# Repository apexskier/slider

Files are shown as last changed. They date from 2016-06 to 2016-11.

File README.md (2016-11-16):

# Slider

Arduino driven mechanical video slider.

[Parts list](https://docs.google.com/a/camlittle.com/spreadsheets/d/1xlj7D98955wYuXj9ept1h3pb_NClaukpYvvVbXTrUsw/edit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)

## Finished project

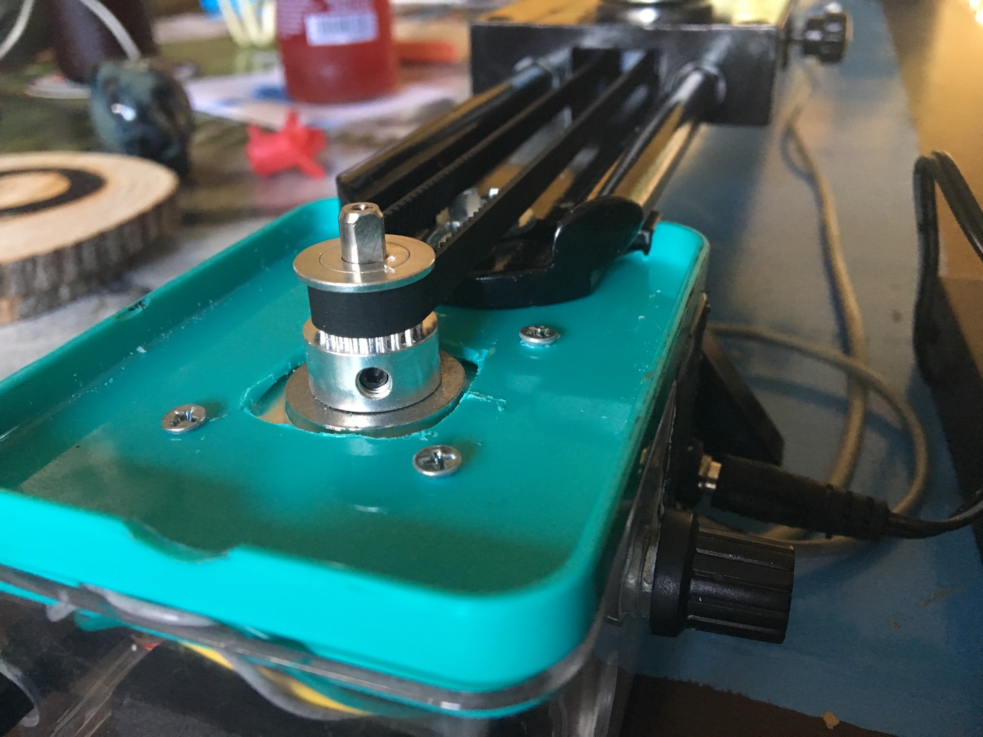
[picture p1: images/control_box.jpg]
Control box and motor housing


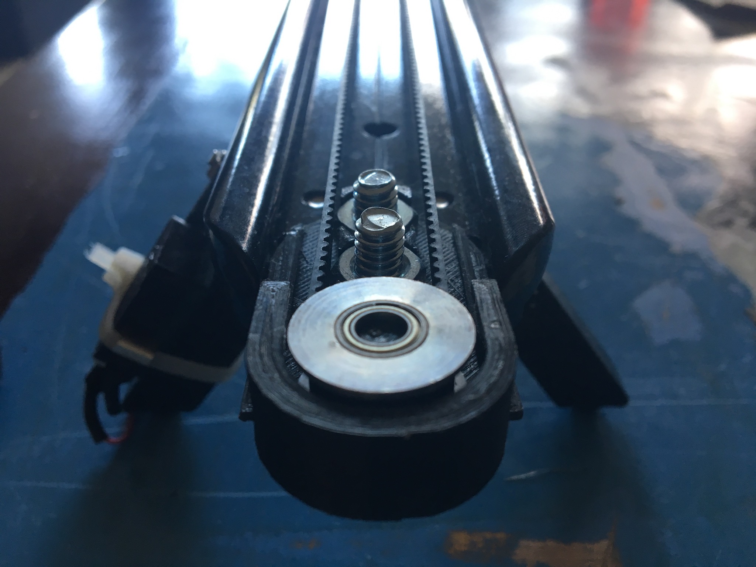
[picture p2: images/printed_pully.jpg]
Timing belt pully and 3D printed mount


## Features

- Auto calibration
- Simple oscillation between each end
- Single direction movement towards the end
- Speed control

## Code

The code is controlled by a basic state machine, paired with global application
state and event triggers. When powered on, the system enters the
CalibratingFindLeft state.

Each button produces buttonDown and buttonUp events as they are pressed and
released.

These are the main state transitions:

```
Stopped
  - main buttonUp -> OscillatingLeft
  - left buttonUp -> MoveLeft
  - right buttonUp -> MoveRight
OscillatingLeft
  - position at left side -> OscillatingRight
  - main buttonDown -> Stopped
OscillatingRight
  - position at right side -> OscillatingLeft
  - main buttonDown -> Stopped
MoveLeft
  - position at left side -> Stopped
MoveRight
  - position at right side -> Stopped
CalibratingFindLeft
  - left buttonDown -> CalibratingFindRight
    (record "0" point)
CalibratingFindRight
  - right buttonDown -> CalibratingReset
    (record slider length)
CalibratingReset
  - position past center -> Stopped
```

In most cases, when in motion buttonDown events on the direction of motion's
switch automatically adjust the internal calibration. There are a few other
event handling checks to safeguard against unexpected behavior.

## Resources

These two DIY slider designs contributed heavily towards ours.

- http://s.co.tt/2015/04/24/diy-motion-control-camera-slider/
- https://learn.adafruit.com/bluetooth-motorized-camera-slider

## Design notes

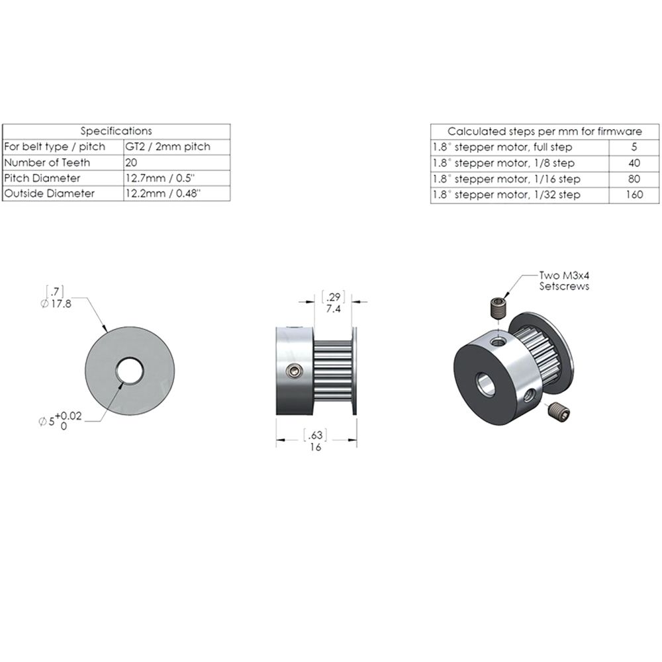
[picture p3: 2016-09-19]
resources/s-l1600.jpg

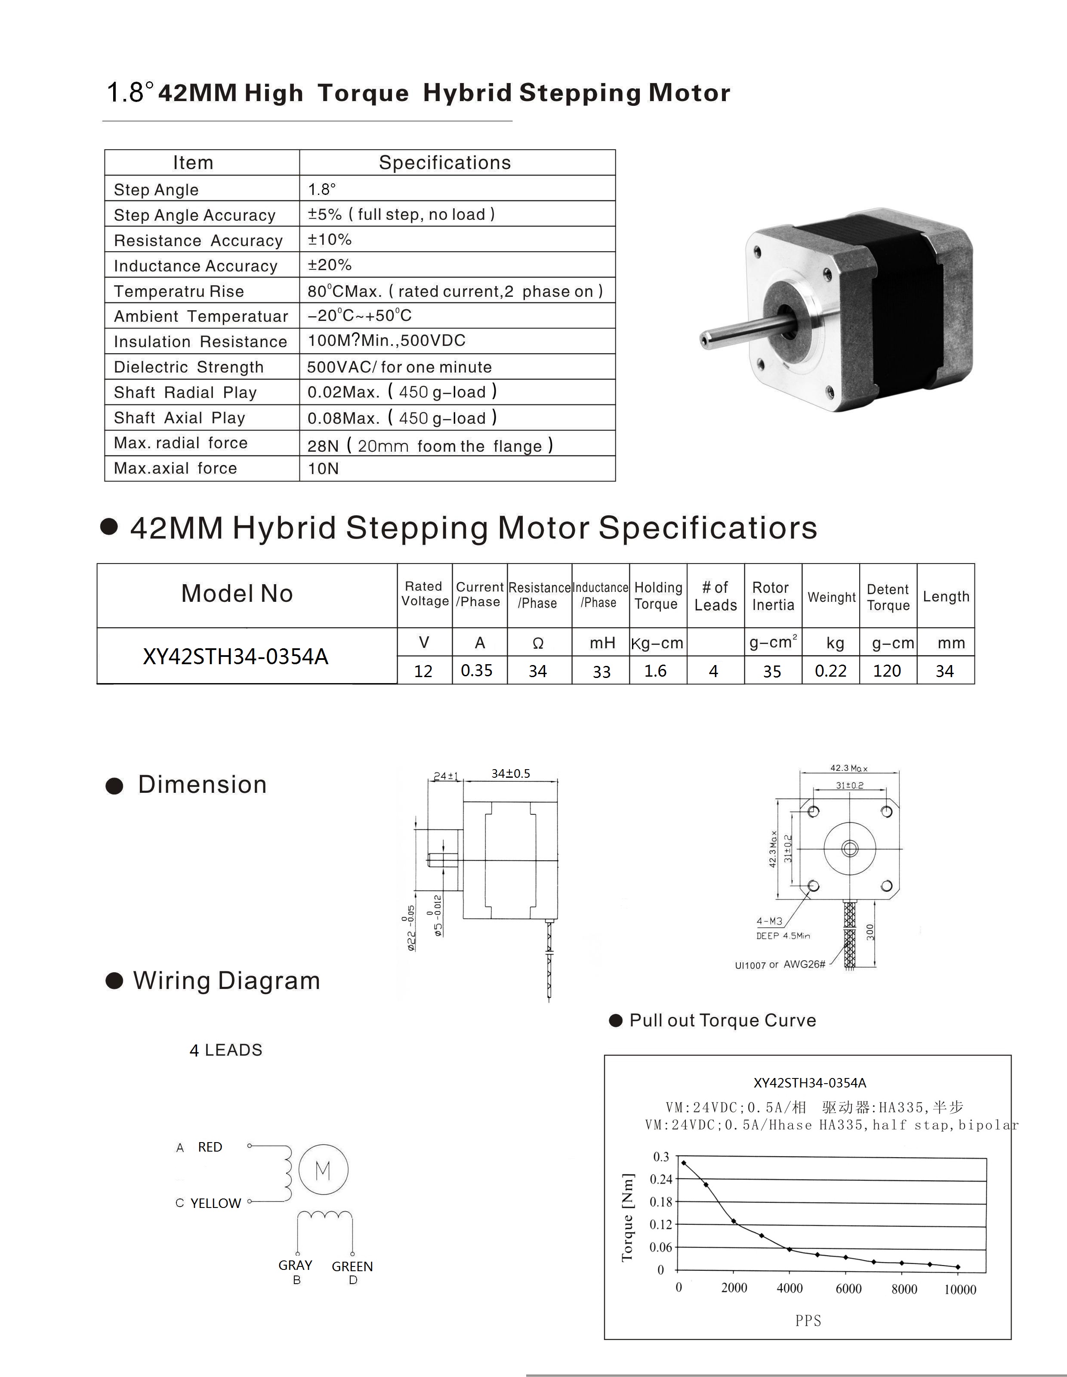
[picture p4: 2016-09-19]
resources/C140-A+datasheet.jpg

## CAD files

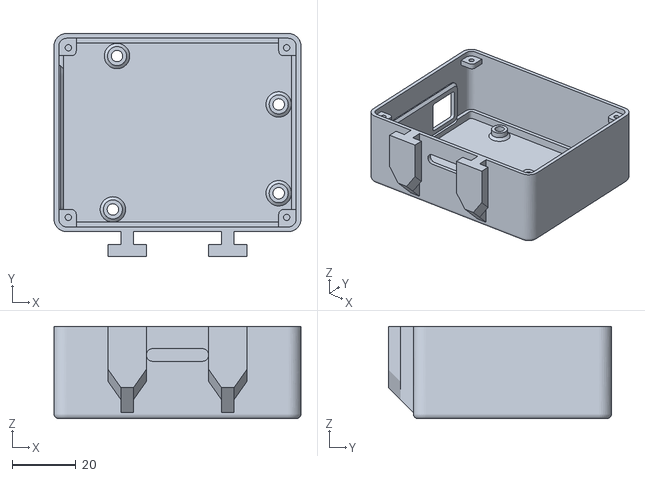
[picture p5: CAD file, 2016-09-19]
resources/Bluetooth_Motorized_Camera_Slider/enclosure-box.stl
77.6 x 70.1 x 29.0

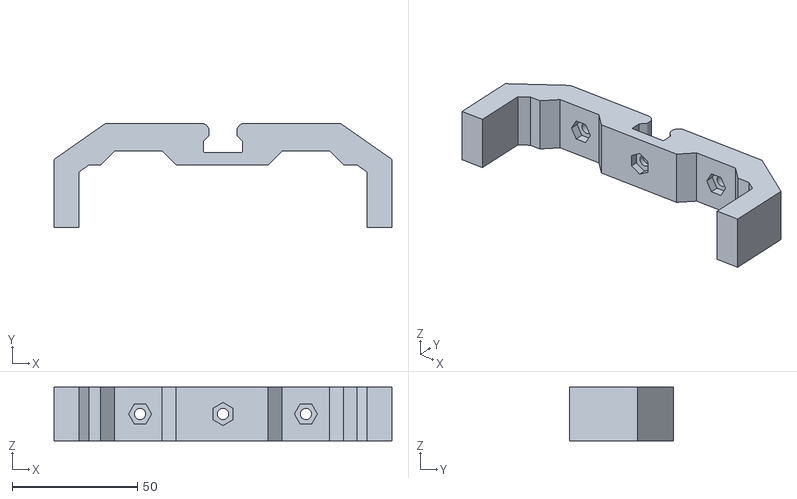
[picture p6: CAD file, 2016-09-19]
resources/Bluetooth_Motorized_Camera_Slider/rail-foot.stl
135.0 x 41.6 x 21.5

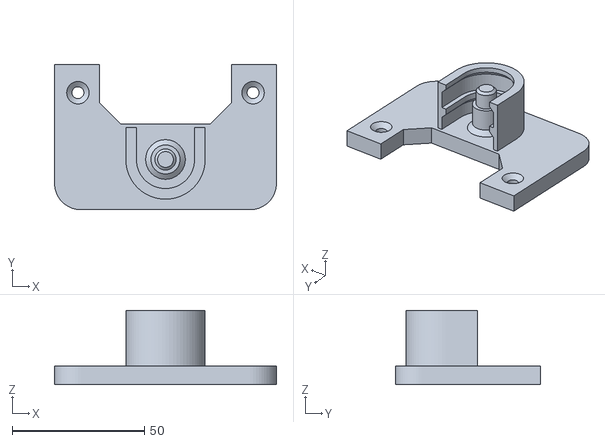
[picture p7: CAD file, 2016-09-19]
resources/Bluetooth_Motorized_Camera_Slider/bearing-mount.stl
83.9 x 55.0 x 28.0

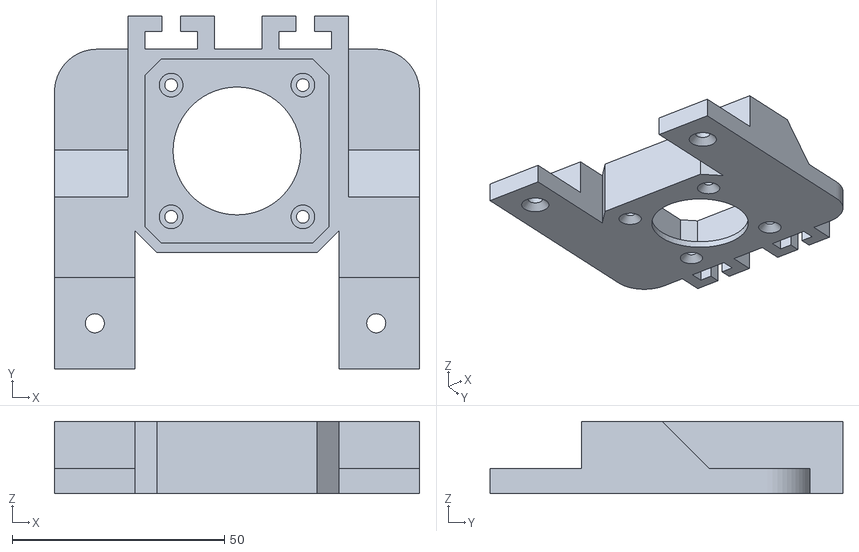
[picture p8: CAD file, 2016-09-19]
resources/Bluetooth_Motorized_Camera_Slider/motor-mount.stl
85.9 x 83.0 x 17.0

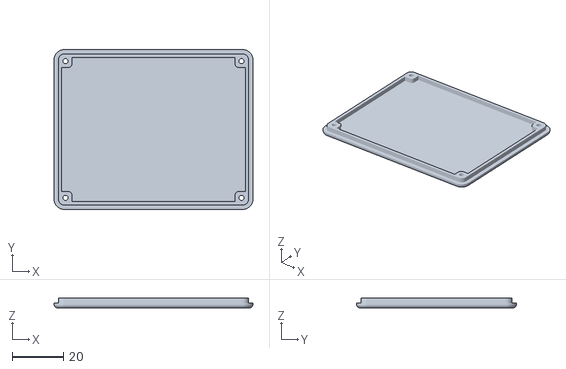
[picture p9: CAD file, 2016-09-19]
resources/Bluetooth_Motorized_Camera_Slider/enclosure-top.stl
77.6 x 62.3 x 4.00

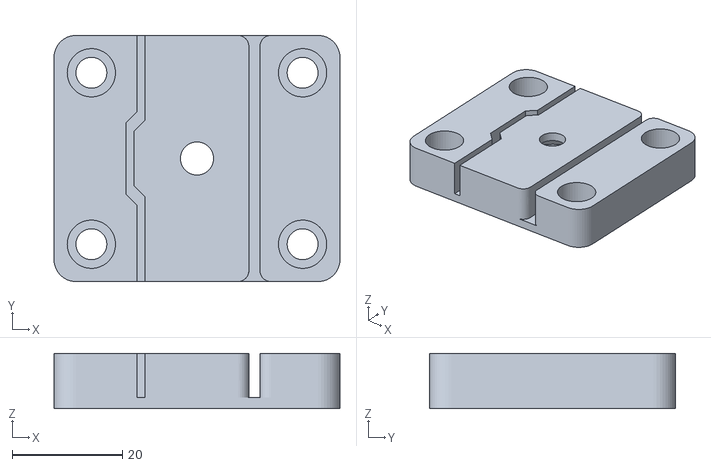
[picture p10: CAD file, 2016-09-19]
resources/Bluetooth_Motorized_Camera_Slider/camera-mount.stl
51.8 x 44.6 x 10.0

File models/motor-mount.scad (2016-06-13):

// rule of thumb
// .2 mm space for friction fit
// .4 mm space for loose fit

wallWidth = 2;

fourCorners = [0, 90, 180, 270];

motorWidth = 42.3 + .2 * 2;
motorCircleDiameter = 22 + .4 * 2;
motorHeight = 34 + .5;
motorDistanceBetweenScrews = 31 + .2;
motorCornerInset = 4;
motorCornerInsetSide = sqrt(2 * pow(motorCornerInset, 2));
motorEdgeHeight = 6;
motorScrewThreadDiameter = 2.7 + .4 * 2;
motorScrewDiameter = 5 + .2 * 2;
motorCounterSinkDepth = 1.8;

module screwHole() {
    translate([0, 0, -1]) {
        cylinder(h = 20, d = motorScrewThreadDiameter, $fn = 80);
    }
    cylinder(h = motorCounterSinkDepth, d1 = motorScrewDiameter, d2 = motorScrewThreadDiameter, $fn = 80);
}

module motorScrewHole() {
    translate([motorDistanceBetweenScrews / 2, motorDistanceBetweenScrews / 2, -0.001]) {
        screwHole();
    }
}

module edgeCutOff() {
    translate([motorWidth / 2, motorWidth / 2, 0]) {
        rotate(45, [0, 0, 1]) {
            translate([-motorCornerInsetSide / 2, -motorCornerInsetSide / 2, 0]) {
                cube([motorCornerInsetSide, motorCornerInsetSide, motorEdgeHeight]);
            }
        }
    }
}

module motorMount() {
    difference() {
        union() {
            difference() {
                translate([-motorWidth / 2 - wallWidth, -motorWidth / 2 - wallWidth, 0]) {
                    cube([motorWidth + wallWidth * 2, motorWidth + wallWidth * 2, motorEdgeHeight]);
                }

                difference() {
                    translate([-motorWidth / 2, -motorWidth / 2, 0]) {
                        cube([motorWidth, motorWidth, motorEdgeHeight + 1]);
                    }

                    for (d = fourCorners) {
                        rotate(d, [0, 0, 1]) edgeCutOff();
                    }
                }
            }

            translate([-motorWidth / 2, -motorWidth / 2, 0]) {
                cube([motorWidth, motorWidth, 2]);
            }
        }

        translate([0, 0, -1]) {
            cylinder(h = 40, d = motorCircleDiameter);
        }

        for (d = fourCorners) {
            rotate(d, [0, 0, 1]) motorScrewHole();
        }
    }
}

translate([0, -(motorWidth + wallWidth * 2) / 2, 0]) {
    rotate(180, [0, 1, 0]) {
        motorMount();
    }
}

mountNutDiameter = 12.8 + .2 * 2;
mountNutHeight = 4.6;
mountScrewDiameter = 6.2 + .4 * 2;
// ensure this is < timing belt diameter
mountDiameter = mountNutDiameter + 3;
mountHoleBetween = 4.2;
mountDistanceToLegs = 4;
mountHoleDiameter = 8;
// distance between middle of two mounting holes
mountSpaceBetween = 4 + 4.2 + 4;

baseThickness = 1.5;
baseLengthExtra = mountDiameter + mountSpaceBetween;
baseWidth = 30 - .2;

module mountNutCutout() {
    translate([0, 0, -50]) {
        linear_extrude(height = 100) {
            circle(d = mountScrewDiameter, $fn = 60);
        }
    }
}

rotate(180, [0, 1, 0]) {
    // above base
    translate([0, 0, baseThickness]) {
        // nut holders
        translate([0, mountDiameter / 2, 0]) {
            difference() {
                hull() {
                    linear_extrude(height = mountNutHeight) {
                        circle(d = mountDiameter, $fn = 30);
                    }

                    translate([0, mountSpaceBetween, 0]) {
                        linear_extrude(height = mountNutHeight) {
                            circle(d = mountDiameter, $fn = 30);
                        }
                    }
                }

                translate([-mountDiameter, mountSpaceBetween + mountDiameter / 2 - wallWidth * 2, -20]) {
                    cube([mountDiameter * 2, 20, 30]);
                }

                translate([0, 0, -1]) {
                    linear_extrude(height = mountNutHeight + 2) {
                        circle(d = mountNutDiameter, $fn = 6);
                    }

                    translate([0, mountSpaceBetween, 0]) {
                        linear_extrude(height = mountNutHeight + 2) {
                            circle(d = mountNutDiameter, $fn = 6);
                        }
                    }
                }
            }
        }
    }
}

boxWidth = motorWidth + (wallWidth + wallWidth + 6.8 + 7) * 2;
echo("boxWidth - walls: ", boxWidth - wallWidth * 4);
boxDepth = motorWidth + wallWidth * 2 + baseLengthExtra + 20;
difference() {
    translate([-boxWidth / 2, -(boxDepth - baseLengthExtra), -wallWidth * 2]) {
        translate([0, 0, wallWidth]) {
            cube([boxWidth, boxDepth, wallWidth]);
        }
        difference() {
            translate([wallWidth, wallWidth, -wallWidth]) {
                cube([boxWidth - wallWidth * 2, boxDepth - wallWidth * 2, wallWidth * 2]);
            }
            translate([wallWidth * 2, wallWidth * 2, -wallWidth * 2]) {
                cube([boxWidth - wallWidth * 4, boxDepth - wallWidth * 4, wallWidth * 4]);
            }
        }
    }

    translate([0, mountDiameter / 2, -1]) {
        mountNutCutout();

        translate([0, mountSpaceBetween, 0]) {
            mountNutCutout();
        }
    }

    translate([0, -(motorWidth + wallWidth * 2) / 2, 0]) {
        rotate(180, [0, 1, 0]) {
            translate([0, 0, -1]) {
                cylinder(h = 40, d = motorCircleDiameter);
            }

            for (d = fourCorners) {
                rotate(d, [0, 0, 1]) motorScrewHole();
            }
        }
    }

    translate([-boxWidth / 2 + 8, 0, 0.01]) {
        translate([0, baseLengthExtra - 8, 0]) {
            rotate(180, [0, 1, 0]) {
                screwHole();
            }
        }

        translate([0, -(boxDepth - baseLengthExtra - 8), 0]) {
            rotate(180, [0, 1, 0]) {
                screwHole();
            }
        }
    }

    translate([boxWidth / 2 - 8, 0,  0.01]) {
        translate([0, baseLengthExtra - 8, 0]) {
            rotate(180, [0, 1, 0]) {
                screwHole();
            }
        }

        translate([0, -(boxDepth - baseLengthExtra - 8), 0]) {
            rotate(180, [0, 1, 0]) {
                screwHole();
            }
        }
    }
}

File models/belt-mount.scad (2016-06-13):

innerWidth = 21; // - .2 * 2;
outerWidth = innerWidth + 5;
innerLength = 41.7; // - .2 * 2;
outerLength = innerLength + 5;
innerHeight = 9.5;
channelDepth = .1;
channelWidth = 2; // - .2 * 2;
boltHeadDiameter = 11; // + .4 * 2;
boltShaftDiameter = 6.22; // + .4 * 2;
washerThickness = 1.64;
washerDiameter = 12.16; // + .4 * 2;

beltWidth = 6;
beltThickness = 1.4;
beltThicknessWithoutTeeth = .7;
beltToBeltThickness = beltThickness + beltThicknessWithoutTeeth;
toothThickness = 1;
toothSpacing = .8;

beltSpaceOuter = 13.5;

module baseCube() {
    cube([outerWidth, outerLength, innerHeight], center = true);
}

module baseCutout() {
    translate([innerWidth / 2 - .2, innerLength / 2 - .2, -50]) {
        cube([100, 100, 100]);
    }
}

module railCutout() {
    railspace = beltThickness * 3;
    railfromend = (outerLength + 2) / 4;

    translate([-railspace - beltToBeltThickness - outerWidth / 8, -(outerLength + 2) / 2, -innerHeight / 2 + 2]) {
        intersection() {
            union() {
                // outer (top)
                difference() {
                    cube([beltToBeltThickness + .4, outerLength + 2, innerHeight]);

                    // left
                    translate([railspace, outerLength + 2 - railfromend - beltToBeltThickness, 0]) {
                        rotate(-45, [0, 0, 1]) {
                            translate([-beltToBeltThickness - 100, -10, 0]) {
                                cube([beltToBeltThickness + 100, outerLength + 2, innerHeight]);
                            }
                        }
                    }

                    // right
                    translate([beltToBeltThickness + railspace, railfromend, 0]) {
                        rotate(180 + 45, [0, 0, 1]) {
                            translate([beltToBeltThickness, -10, 0]) {
                                cube([beltToBeltThickness + 100, outerLength + 2, innerHeight]);
                            }
                        }
                    }
                }

                // left
                translate([railspace, outerLength + 2 - railfromend - beltToBeltThickness, 0]) {
                    rotate(-45, [0, 0, 1]) {
                        translate([0, -10, 0]) {
                            cube([beltToBeltThickness + .4, outerLength + 2, innerHeight]);
                        }
                    }
                }

                // right
                translate([beltToBeltThickness + railspace, railfromend, 0]) {
                    rotate(180 + 45, [0, 0, 1]) {
                        translate([0, -10, 0]) {
                            cube([beltToBeltThickness + .4, outerLength + 2, innerHeight]);
                        }
                    }
                }

                // inner
                difference() {
                    translate([railspace, 0, 0]) {
                        cube([beltToBeltThickness + .4, outerLength + 2, innerHeight]);
                    }

                    // right
                    translate([beltToBeltThickness + railspace, railfromend, 0]) {
                        rotate(180 + 45, [0, 0, 1]) {
                            translate([-beltToBeltThickness - 4, -10, 0]) {
                                cube([beltToBeltThickness + 4, outerLength + 2, innerHeight]);
                            }
                        }
                    }

                    // left
                    translate([railspace, outerLength + 2 - railfromend - beltToBeltThickness, 0]) {
                        rotate(-45, [0, 0, 1]) {
                            translate([beltToBeltThickness, -10, 0]) {
                                cube([beltToBeltThickness + 10, outerLength + 2, innerHeight]);
                            }
                        }
                    }
                }
            }

            cube([beltThickness + railspace + .4, outerLength + 2, innerHeight]);
        }
    }
}

// this gives an idea of where the belt will slide
// cube(beltSpaceOuter, center = true);

difference() {
    baseCube();

    // corners
    baseCutout();
    scale([1, -1, 1]) baseCutout();
    scale([-1, 1, 1]) baseCutout();
    scale([-1, -1, 1]) baseCutout();

    translate([0, 0, -50]) {
        cylinder(h = 100, d = boltShaftDiameter + .4 * 2, $fn = 60);
    }
    translate([0, 0, -innerHeight / 2 + 1]) {
        cylinder(h = 100, d = boltHeadDiameter + .2 * 2, $fn = 60);
    }

    translate([0, 1.6, 0]) {
        railCutout();
    }

    beltSlidingWidth = beltThickness * 3;
    translate([(-beltSlidingWidth + beltSpaceOuter - beltThickness) / 2, -(outerLength + 2) / 2, -innerHeight / 2 + 2]) {
        cube([beltSlidingWidth, outerLength + 2, innerHeight]);
    }
}

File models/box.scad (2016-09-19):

// rule of thumb
// .2 mm space for friction fit
// .4 mm space for loose fit

wallWidth = 2;

fourCorners = [0, 90, 180, 270];

motorWidth = 42.3 + .2 * 2;
motorHeight = 34 + .5;
motorCornerInset = 4;
motorCornerInsetSide = sqrt(2 * pow(motorCornerInset, 2));
motorEdgeHeight = 6;
motorScrewThreadDiameter = 2.7 + .4 * 2;

mountNutDiameter = 12.8 + .2 * 2;
// ensure this is < timing belt diameter
mountDiameter = mountNutDiameter + 3;
// distance between middle of two mounting holes
mountSpaceBetween = 4 + 4.2 + 4;

baseThickness = 1.5;
baseLengthExtra = mountDiameter + mountSpaceBetween;
baseWidth = 30 - .2;

boxWidth = motorWidth + (wallWidth + wallWidth + 6.8 + 7) * 2;
boxDepth = motorWidth + wallWidth * 2 + baseLengthExtra + 20;
motorRise = 7.5;
boxHeight = 31.5 + motorRise + wallWidth * 2;

nutDiameter = 7.1 + .4 * 2;

switchHeadSide = 16 + .4 * 2;
dialDiameter = 7 + .4 * 2;
batteryPlugDiameter = 11 + .4;
switchCableWidth = 3.3;
switchCableHeight = 2.3;

module screwHole() {
    linear_extrude(height = boxHeight - wallWidth) {
        circle(d = motorScrewThreadDiameter, $fn = 80);
    }
}

module nut() {
    linear_extrude(height = boxHeight - wallWidth * 6) {
        circle(d = nutDiameter, $fn = 6);
    }
}

module nutHolder() {
    height = 10;
    translate([-7, -7, boxHeight - wallWidth * 3 - .2 - height]) {
        cube([14, 14, height]);
    }
}

module edgeCutOff() {
    translate([motorWidth / 2, motorWidth / 2, 0]) {
        rotate(45, [0, 0, 1]) {
            translate([-motorCornerInsetSide / 2, -motorCornerInsetSide / 2, 0]) {
                cube([motorCornerInsetSide, motorCornerInsetSide, motorEdgeHeight]);
            }
        }
    }
}

module motorMount() {
    union() {
        translate([0, 0, motorRise]) {
            difference() {
                translate([-motorWidth / 2 - wallWidth, -motorWidth / 2 - wallWidth, 0]) {
                    cube([motorWidth + wallWidth * 2, motorWidth + wallWidth * 2, motorEdgeHeight]);
                }

                difference() {
                    translate([-motorWidth / 2, -motorWidth / 2, 0]) {
                        cube([motorWidth, motorWidth, motorEdgeHeight + 1]);
                    }

                    for (d = fourCorners) {
                        rotate(d, [0, 0, 1]) edgeCutOff();
                    }
                }
            }
        }

        translate([-motorWidth / 2 - wallWidth, -motorWidth / 2 - wallWidth, 0]) {
            cube([motorWidth + wallWidth * 2, motorWidth + wallWidth * 2, motorRise]);
        }
    }
}

module switchCable() {
    rotate(90, [1, 0, 0])
        scale([1, switchCableHeight / switchCableWidth, 1])
            cylinder(h = 20, d = switchCableWidth, $fn = 30);
}

motorCtlWidth = 1.65;
motorCtlLength = 27;
translate([motorCtlLength / 2 + wallWidth, -boxDepth + baseLengthExtra + wallWidth * 3, wallWidth]) {
    rotate(90, [0, 0, 1]) {
        difference() {
            translate([0, 0, wallWidth]) {
                cube([motorCtlWidth + wallWidth * 2, motorCtlLength + wallWidth * 2, .6]);
                translate([0, 0, -wallWidth]) {
                    cube([motorCtlWidth + wallWidth * 2, motorCtlLength + wallWidth * 2, wallWidth]);
                }
            }
            translate([wallWidth, wallWidth, wallWidth]) {
                cube([motorCtlWidth, motorCtlLength, 10]);
            }
        }
    }
}

arduWidth = 1;
arduLength = 33.6;
mirror(v = [1, 0, 0])
translate([motorWidth / 2 + wallWidth * 2, -boxDepth + baseLengthExtra + wallWidth * 1, wallWidth]) {
    difference() {
        translate([0, 0, wallWidth]) {
            cube([arduWidth + wallWidth * 2, arduLength + wallWidth * 2, .6]);
            translate([0, 0, -wallWidth]) {
                cube([arduWidth + wallWidth * 2, arduLength + wallWidth * 2, wallWidth]);
            }
        }
        translate([wallWidth, wallWidth, wallWidth]) {
            cube([arduWidth, arduLength, 10]);
        }
    }
}

difference() {
    union() {
        translate([-boxWidth / 2, -(boxDepth - baseLengthExtra), 0]) {
            difference() {
                // remember to account for the floor and the ceiling!
                cube([boxWidth, boxDepth, boxHeight]);
                translate([wallWidth, wallWidth, wallWidth]) {
                    cube([boxWidth - wallWidth * 2, boxDepth - wallWidth * 2, 100]);
                }
                // lip where top attaches
                lipWidth = wallWidth - .4;
                translate([lipWidth, lipWidth, boxHeight - wallWidth * 2 - .2]) {
                    cube([boxWidth - lipWidth * 2, boxDepth - lipWidth * 2, 100]);
                }

                // hide walls
                // translate([-1, -1, wallWidth]) {
                //     cube([boxWidth + 2, boxDepth + 2, boxHeight + 2]);
                // }
            }

            // ftdi channel
            cube([6, 10, 24]);
        }

        // screwmounts
        translate([0, 0, wallWidth]) {
            translate([-boxWidth / 2 + 8, 0, 0]) {
                translate([0, baseLengthExtra - 8, 0]) {
                    nutHolder();
                }

                translate([0, -(boxDepth - baseLengthExtra - 8), 0]) {
                    nutHolder();
                }
            }

            translate([boxWidth / 2 - 8, 0, 0]) {
                translate([0, baseLengthExtra - 8, 0]) {
                    nutHolder();
                }

                translate([0, -(boxDepth - baseLengthExtra - 8), 0]) {
                    nutHolder();
                }
            }
        }
    }

    // screwmounts
    translate([0, 0, wallWidth]) {
        translate([-boxWidth / 2 + 8, 0, 0]) {
            translate([0, baseLengthExtra - 8, 0]) {
                screwHole();
                nut();
            }

            translate([0, -(boxDepth - baseLengthExtra - 8), 0]) {
                screwHole();
                nut();
            }
        }

        translate([boxWidth / 2 - 8, 0, 0]) {
            translate([0, baseLengthExtra - 8, 0]) {
                screwHole();
                nut();
            }

            translate([0, -(boxDepth - baseLengthExtra - 8), 0]) {
                screwHole();
                nut();
            }
        }
    }

    translate([boxWidth / 2, 0, boxHeight / 2]) {
        // dial hole
        translate([0, -motorWidth / 2 - wallWidth, 0]) {
            translate([-10, 0, 0]) {
                rotate(90, [0, 1, 0]) {
                    cylinder(d = dialDiameter, h = 20, $fn = 40);
                }
            }

            translate([-.4, 0, 0]) {
                rotate(90, [0, 1, 0]) {
                    linear_extrude(height = 1) {
                        innerR = 11;
                        outerR = 13.5;
                        difference() {
                            color( [0, 1, 0] ) {
                                translate([0, outerR - innerR, 0])
                                    circle(r = outerR);
                            }

                            circle(r = innerR);

                            color( [0, 0, 1] ) {
                                translate([0, -outerR, 0])
                                    square(outerR * 3);
                            }
                        }
                    }
                }
            }
        }

        // button hole
        translate([-switchHeadSide / 2 - 20, 0, -switchHeadSide / 2])
            cube([100, switchHeadSide, switchHeadSide]);
        sHInside = switchHeadSide + 4;
        translate([-sHInside - wallWidth + .8, -2, -sHInside / 2])
            cube([20, sHInside, sHInside]);
    }

    // FTDI cable
    translate([-boxWidth / 2, -motorWidth - 20, wallWidth * 2]) {
        translate([-5, 0, 0]) {
            cube([20, 2.55 + .4 * 2, 15.2 + .4 * 2]);
        }
    }

    // battery plug
    translate([10 - boxWidth / 2, baseLengthExtra - batteryPlugDiameter / 2 - wallWidth, batteryPlugDiameter / 2 + wallWidth]) {
        rotate(-90, [0, 1, 0]) {
            cylinder(d = batteryPlugDiameter, h = 20, $fn = 40);
        }
    }

    // switch holes
    translate([0, baseLengthExtra + 10, boxHeight / 2]) {
        hull() {
            switchCable();
            translate([0, 0, switchCableHeight]) {
                switchCable();
            }
        }
    }

    translate([boxWidth / 2 - .4, -boxDepth + baseLengthExtra + wallWidth, wallWidth]) {
        rotate(90, [1, 0, 0]) {
            rotate(90, [0, 1, 0]) {
                text("https://github.com/apexskier/slider v1.0.0", size = 3);
            }
        }
    }
}

translate([0, -(motorWidth + wallWidth * 2) / 2, 0]) {
    motorMount();
}

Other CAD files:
models/pully-mount.scad

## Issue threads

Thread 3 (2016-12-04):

Persist calibration information

apexskier, 2016-12-04:
I think I can save the left and right positions/size/whatever to persistent storage and avoid a full calibration on every reboot. This will require some sort of user input pattern to trigger calibration.

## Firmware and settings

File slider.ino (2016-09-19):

#include <AccelStepper.h>

#define DEBUG true
#define MAX_SPEED 220

enum EventType {
  Null,
  ButtonUp,
  ButtonDown
};

class Event {
 public:
  Event() {};
  const static EventType type = Null;
};

class NullEvent: public Event {};

class ButtonEvent: public Event {
 public:
  ButtonEvent(unsigned long timeSince) {
    this->timeSince = timeSince;
  };
  unsigned long timeSince;
};

class ButtonDownEvent: public ButtonEvent {
 public:
  ButtonDownEvent(unsigned long timeSince): ButtonEvent(timeSince) {};
  const static EventType type = ButtonDown;
};

class ButtonUpEvent: public ButtonEvent {
 public:
  ButtonUpEvent(unsigned long timeSince): ButtonEvent(timeSince) {};
  const static EventType type = ButtonUp;
};

class Input {
 public:
  Input(int pin) {
    this->pin = pin;
    this->currentValue = LOW;
    this->lastEvent = Null;
    pinMode(pin, INPUT);

    unsigned long now = millis();
    this->lastChangeTime = 0;
    this->lastUpdateTime = 0;
  };

  /**
   * Update the value and internals of an input and generate events.
   * Rate limited
   */
  void update() {
    unsigned long now = millis();
    if (now - lastUpdateTime <= RATE_LIMIT) {
      return;
    }

    int value = digitalRead(pin);
    // Serial.println("read " + String(value) + " on pin " + String(pin));
    // event will be generated
    if (value != currentValue) {
      if (lastEvent != Null) {
        Serial.println("Warning! Unconsumed event in queue for input " + String(pin));
      }
      if (value) {
        lastEvent = ButtonDown;
        if (DEBUG) {
          Serial.println("GENERATE ButtonDownEvent on " + String(pin));
        }
      } else {
        lastEvent = ButtonUp;
        if (DEBUG) {
          Serial.println("GENERATE ButtonUpEvent on " + String(pin));
        }
      }
      lastChangeTime = now;
      currentValue = value;
    }
    lastUpdateTime = now;
  };

  EventType consumeEvent() {
    if (lastEvent == Null) {
      return Null;
    }
    if (DEBUG) {
      switch (lastEvent) {
        case ButtonUp:
          Serial.println("CONSUME ButtonUpEvent on " + String(pin));
          break;
        case ButtonDown:
          Serial.println("CONSUME ButtonDownEvent on " + String(pin));
          break;
        case Null:
          Serial.println("CONSUME NullEvent on " + String(pin));
          break;
        default:
          Serial.println("CONSUME Unknown Event on " + String(pin));
      }
    }
    EventType e = lastEvent;
    lastEvent = Null;
    return e;
  };

 protected:
  int pin;
  int currentValue;
  unsigned long lastChangeTime;
  unsigned long lastUpdateTime;
  EventType lastEvent;
  const static unsigned long RATE_LIMIT = 10;
};

// const int LED = 13;    // DO NOT USE ----------------- v  ----
AccelStepper stepper(AccelStepper::FULL4WIRE, 10, 11, 12, 13);

const int PADDING = 10;
const float CALIBRATION_SPEED = 100;

long sliderLength = 0;

Input* startButton = NULL;
Input* leftSwitch = NULL;
Input* rightSwitch = NULL;
int speedPotPin = A0;

enum State {
  Stopped,
  OscillatingLeft,
  OscillatingRight,
  MoveLeft,
  MoveRight,
  CalibratingFindLeft,
  CalibratingFindRight,
  CalibratingReset
};

String stateName(State s) {
  switch (s) {
    case Stopped:
      return "Stopped";
    case OscillatingLeft:
      return "OscillatingLeft";
    case OscillatingRight:
      return "OscillatingRight";
    case MoveLeft:
      return "MoveLeft";
    case MoveRight:
      return "MoveRight";
    case CalibratingFindLeft:
      return "CalibratingFindLeft";
    case CalibratingFindRight:
      return "CalibratingFindRight";
    case CalibratingReset:
      return "CalibratingReset";
  }
  return "UnknownState";
}

State currentState = Stopped;

void setSliderSpeed() {
    float speed = analogToSpeed(1023 - analogRead(speedPotPin));
    float currentSpeed = stepper.speed();
    if (abs(abs(currentSpeed) - speed) > 2) {
        if (currentSpeed > 0) {
            stepper.setSpeed(speed);
        } else {
            stepper.setSpeed(-speed);
        }
        if (DEBUG) {
            Serial.println("SETTING SPEED: " + String(speed));
        }
    }
}

float analogToSpeed(int value) {
  //                     v -- max analog value
  return (float(value) / 1023.0) * MAX_SPEED;
}

void startMovingLeft() {
  if (DEBUG) {
    Serial.println("MOVE LEFT");
  }
  int speed = stepper.speed();
  if (speed > 0) {
    speed = -speed;
  }
  stepper.setSpeed(speed);
}

void startMovingRight() {
  if (DEBUG) {
    Serial.println("MOVE RIGHT");
  }
  int speed = stepper.speed();
  if (speed < 0) {
    speed = -speed;
  }
  stepper.setSpeed(speed);
}

void markLeft() {
  int speed = stepper.speed();
  sliderLength = sliderLength - stepper.currentPosition();
  stepper.setCurrentPosition(0);
  stepper.setSpeed(speed);
  if (DEBUG) {
    Serial.println("MARK LEFT");
  }
}

void markRight() {
  sliderLength = stepper.currentPosition();
  if (DEBUG) {
    Serial.println("MARK RIGHT (" + String(sliderLength) + ")");
  }
}

void changeState(State s) {
  if (DEBUG) {
    Serial.println("STATE CHANGE: from " + stateName(currentState) + " to " + stateName(s));
  }
  currentState = s;
}

void setup() {
  startButton = new Input(8);
  leftSwitch = new Input(2);
  rightSwitch = new Input(4);

  stepper.setMaxSpeed(MAX_SPEED);
  stepper.setAcceleration(1);

  // initialize the serial port:
  Serial.begin(9600);

  delay(300);

  // calibrate();
  changeState(CalibratingFindLeft);
  stepper.setSpeed(CALIBRATION_SPEED);
  startMovingLeft();
}

void loop() {
  // Serial.println("-------------------------");
  State loopState = currentState;

  // Read inputs
  startButton->update();
  leftSwitch->update();
  rightSwitch->update();

  EventType startEvent = startButton->consumeEvent();
  EventType leftEvent = leftSwitch->consumeEvent();
  EventType rightEvent = rightSwitch->consumeEvent();

  // Navigate through state machine
  // * Event based
  switch (startEvent) {
    case ButtonUp:
      switch (loopState) {
        case Stopped:
          // TODO: choose direction
          if (stepper.speed() > 0) {
            changeState(OscillatingRight);
          } else {
            changeState(OscillatingLeft);
          }
        break;
        case CalibratingReset:
          changeState(Stopped);
          break;
      }
      break;
    case ButtonDown:
      switch (loopState) {
        case OscillatingLeft:
        case OscillatingRight:
        case MoveLeft:
        case MoveRight:
        case CalibratingReset:
          changeState(Stopped);
          break;
      }
  }

  switch (leftEvent) {
    case ButtonUp:
      switch (loopState) {
        case Stopped:
          changeState(MoveLeft);
          startMovingLeft();
          break;
      }
      break;
    case ButtonDown:
      switch (loopState) {
        case OscillatingLeft:
          markLeft();
          startMovingRight();
          changeState(OscillatingRight);
          break;
        case CalibratingFindLeft:
          markLeft();
          startMovingRight();
          changeState(CalibratingFindRight);
          break;
        case CalibratingReset:
          markLeft();
          startMovingRight();
          changeState(CalibratingFindRight);
          break;
        case MoveLeft:
          markLeft();
          startMovingRight();
          changeState(Stopped);
          break;
      }
  }

  switch (rightEvent) {
    case ButtonUp:
      switch (loopState) {
        case Stopped:
          changeState(MoveRight);
          startMovingRight();
          break;
      }
      break;
    case ButtonDown:
      switch (loopState) {
        case OscillatingRight:
          markRight();
          startMovingLeft();
          changeState(OscillatingLeft);
          break;
        case CalibratingFindRight:
          markRight();
          startMovingLeft();
          changeState(CalibratingReset);
          break;
        case CalibratingReset:
          markRight();
          startMovingLeft();
          changeState(CalibratingFindLeft);
          break;
        case MoveRight:
          markRight();
          startMovingLeft();
          changeState(Stopped);
          break;
      }
  }

  int sliderPosition = stepper.currentPosition();

  // * global state based // TODO: better word than state here
  if (sliderPosition < PADDING) {
    switch (loopState) {
      case OscillatingLeft:
        startMovingRight();
        changeState(OscillatingRight);
        break;
      case MoveLeft:
        startMovingRight();
        changeState(Stopped);
        break;
    }
  } else if (sliderPosition > sliderLength - PADDING) {
    switch (loopState) {
      case OscillatingRight:
        startMovingLeft();
        changeState(OscillatingLeft);
        break;
      case MoveRight:
        startMovingLeft();
        changeState(Stopped);
        break;
    }
  }

  if (loopState == CalibratingReset &&
      sliderPosition < sliderLength / 2) {
    changeState(Stopped);
  }

  if (!(loopState == CalibratingFindLeft ||
        loopState == CalibratingFindRight ||
        loopState == CalibratingReset)) {
    setSliderSpeed();
  }

  // State actions
  switch (loopState) {
    case OscillatingLeft:
    case MoveLeft:
    case OscillatingRight:
    case MoveRight:
    case CalibratingFindLeft:
    case CalibratingFindRight:
    case CalibratingReset:
      stepper.runSpeed();
      break;
    case Stopped:
    default:
      // pass!
      break;
  }
}

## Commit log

2016-05-05 Basic i/o code, basic (not correct) circuit schematic
    [slider.fzz]
2016-05-05 Got calibration v1 working.
2016-05-13 Implemented padding stuff in oscillation.
    [slider.ino]
2016-05-13 Debugged and fixed a bunch of stuff.
    [slider.ino]
2016-05-14 Added README and pully-mount
    [pully-mount.scad]
2016-05-16 Progress
    - Worked on pully mount for actual hardware dimensions and mounting
    - Started on motor mount/electronics enclosure
    - Bugfixes to code
    [motor-mount.scad, pully-mount.scad]
2016-06-13 Updated and adding models.
    [belt-mount.scad, motor-mount.scad, pully-mount.scad]
2016-06-13 Added openscad model for box bottom.
    [box.scad]
2016-09-19 Old work. Project is done!!
    [bearing-mount.stl, box.scad, camera-mount.stl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]
